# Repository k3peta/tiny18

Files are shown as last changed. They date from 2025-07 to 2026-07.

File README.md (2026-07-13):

# Tiny18

Tiny18 is a compact, 18-key wireless split keyboard designed for Japanese input. Each half uses a Seeed Studio XIAO nRF52840 and ZMK firmware.

日本語の説明は [`README.ja.md`](README.ja.md) を参照してください。

[Download the latest firmware](https://github.com/k3peta/zmk-config-tiny18/releases/latest) · [Firmware source](https://github.com/k3peta/zmk-config-tiny18) · [Keymap](https://github.com/k3peta/zmk-config-tiny18#default-keymap)

## Features

- 18 keys total (9 per half)
- Wireless split using Bluetooth Low Energy
- Seeed Studio XIAO nRF52840 controllers
- Kailh Choc (PG1350) switch footprints
- Diodeless, direct-pin wiring
- Reversible PCB: the same board is used for both halves
- Battery connector and hardware power switch on each half
- ZMK Studio support on the right/central half over USB

## Repository contents

This repository contains the production outputs for the PCB. The ZMK source and downloadable UF2 firmware are kept in the separate [zmk-config-tiny18](https://github.com/k3peta/zmk-config-tiny18) repository so that firmware builds remain small and reproducible.

| Path | Purpose |
| --- | --- |
| [`production/Tiny18mini.zip`](production/Tiny18mini.zip) | Gerber and drill files for PCB fabrication |
| [`production/bom.csv`](production/bom.csv) | Bill of materials exported from KiCad |
| [`production/positions.csv`](production/positions.csv) | Component placement data |
| [`production/designators.csv`](production/designators.csv) | Reference designator data |
| [`production/netlist.ipc`](production/netlist.ipc) | IPC-D-356 netlist for fabrication checks |

See [`production/README.md`](production/README.md) before ordering boards.

## Firmware

Prebuilt firmware is distributed from the [firmware Releases page](https://github.com/k3peta/zmk-config-tiny18/releases/latest). A release contains:

- `tiny18-right.uf2` — right half and Bluetooth central
- `tiny18-left.uf2` — left half and Bluetooth peripheral
- `settings-reset.uf2` — clears saved Bluetooth and split settings
- `SHA256SUMS` — checksums for the UF2 files

The right and left files are not interchangeable. Flashing the wrong file will not normally damage the controller; enter the bootloader again and flash the correct file.

### Flashing

1. Turn the keyboard's battery power switch off. Connect one half to the computer with a USB data cable.
2. Double-press the XIAO reset button. A drive named `XIAO-SENSE` should appear.
3. Copy the matching UF2 file to that drive:
   - right half: `tiny18-right.uf2`
   - left half: `tiny18-left.uf2`
4. Repeat for the other half, then disconnect USB and turn both halves on.
5. Pair the Bluetooth device named `tiny18` from the host computer.

For first-time setup, or when the halves no longer pair, flash `settings-reset.uf2` to both halves first. Enter the bootloader again, then flash the matching right and left firmware.

After clearing settings, remove the old `tiny18` entry from the host's Bluetooth settings before pairing again.

## Safety and scope

- Verify battery polarity before connecting a LiPo battery. Reversed polarity can damage the controller or battery.
- Turn battery power off while flashing over USB.
- These files are provided as-is. PCB fabrication, assembly, battery selection, and physical testing remain the builder's responsibility.
- The repository does not currently include a case or switch plate.

## License

The hardware production files in this repository are licensed under [CERN-OHL-P-2.0](LICENSE); see [`NOTICE`](NOTICE). Firmware is licensed separately under the MIT License in the firmware repository. Third-party components retain their own licenses.

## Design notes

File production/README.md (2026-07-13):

# Production files

`Tiny18mini.zip` contains the Gerber and drill files for one reversible Tiny18 PCB. Order two copies to build a complete keyboard.

## Before ordering

- Upload `Tiny18mini.zip` to the PCB manufacturer's Gerber viewer and confirm the board outline, copper, solder mask, and drill layers.
- Do not rename or unpack individual Gerber files unless the manufacturer requires it.
- This is a reversible design. The same PCB is assembled in opposite orientations for the left and right halves.
- The BOM is exported per PCB. A complete split keyboard requires two XIAO nRF52840 controllers, 18 Kailh Choc switches, two power switches, and the corresponding battery hardware.
- The two battery-connector designators represent alternative front/back placements on a reversible PCB. Populate only the footprint appropriate to the assembled side.
- Confirm component orientation and battery polarity against the physical PCB before applying power.

The CSV and IPC files are manufacturing references. They are not firmware and are not needed when flashing an assembled keyboard.

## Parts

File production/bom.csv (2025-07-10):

Designator | Footprint | Quantity | Value | LCSC Part #
BT1_2, BT1 | JST_GH_SM02B-GHS-TB_1x02-1MP_P1.25mm_Horizontal | 2 | Battery_Cell
SW1, SW2, SW3, SW4, SW5, SW6, SW7, SW8, SW9 | SW_PG1350_reversible | 9 | SW_Push
SW10 | TGSW_MSK-12D19 | 1 | SW_SPDT
U1 | XIAO_ble | 1 | xiao-ble

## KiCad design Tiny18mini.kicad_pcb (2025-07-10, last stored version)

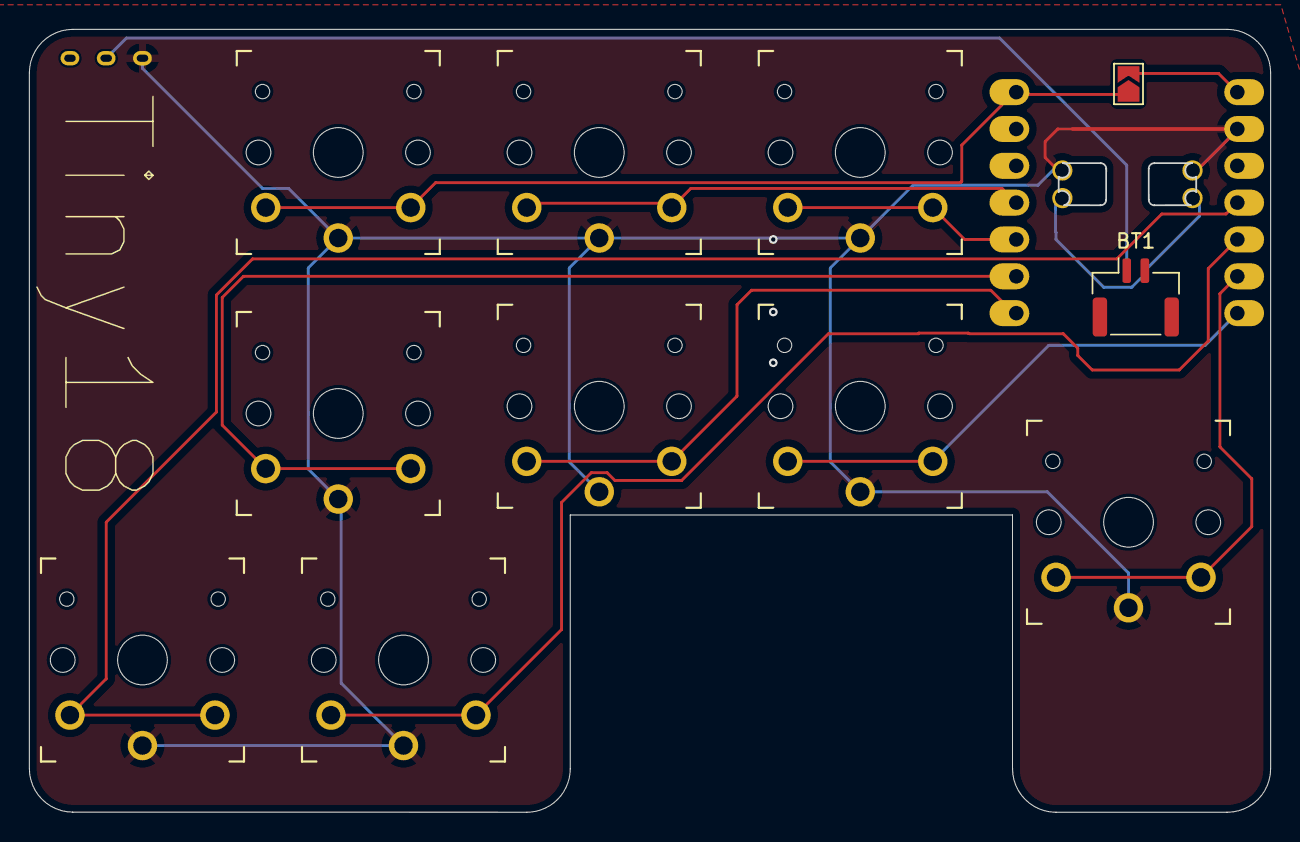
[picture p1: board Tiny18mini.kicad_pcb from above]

Board: 2 copper layers, 85.6 x 54.0 mm, 13 parts (1 on the bottom side), 12 nets.

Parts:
BT1, BT1#2: Battery_Cell; JST_GH_SM02B-GHS-TB_1x02-1MP_P1.25mm_Horizontal
SW1, SW2, SW3, SW4, SW5, SW6, SW7, SW8, SW9: SW_Push; SW_PG1350_reversible
SW10: SW_SPDT; TGSW_MSK-12D19
U1: xiao-ble; XIAO_ble

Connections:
Bat: BT1.1 (+), BT1#2.1 (+), U1.19 (BAT)
D0: SW1.2, U1.1 (A2/0.02_H)
D1: SW2.2, U1.4 (A11/0.29)
D2: SW3.2, U1.5 (A8_SDA/0.04_H)
D3: SW4.2, U1.6 (A9_SCL/0.05_H)
D4: SW5.2, U1.7 (B8_TX/1.11)
D5: SW6.2, U1.8 (B9_RX/1.12)
D6: SW7.2, U1.9 (A7_SCK/1.13)
D7: SW8.2, U1.10 (A5_MISO/1.14)
D8: SW9.2, U1.11 (A6_MOSI/1.15)
GND: SW1.1, SW2.1, SW3.1, SW4.1, SW5.1, SW6.1, SW7.1, SW8.1, SW9.1, SW10.1 (A), U1.13 (GND), U1.20 (GND)
unnamed: BT1.2 (-), BT1#2.2 (-), SW10.2 (B)
